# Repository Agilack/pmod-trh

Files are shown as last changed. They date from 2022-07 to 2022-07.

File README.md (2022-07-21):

PMOD Temperature and Humidity
=============================

This PMOD use an Si7021 sensor for temperature and humidity measurement.

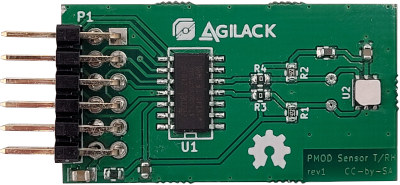
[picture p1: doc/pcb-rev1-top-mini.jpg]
Picture of PMOD-trh rev1


CAD source
----------

This board has been designed using KiCad EDA (version 6). All sources files
(schematics, routing, ...) are available into the `prj-kicad` folder. You can
re-use this design under terms of the Creative Commons  ShareAlike license
(CC-by-SA).

<table>
<tr>
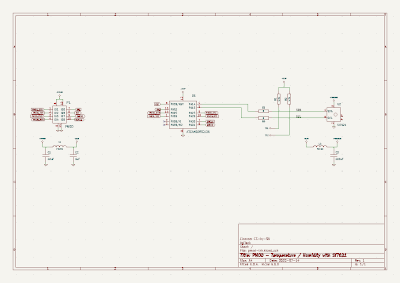
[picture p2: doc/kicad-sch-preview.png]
KiCad schematics
<td></td>
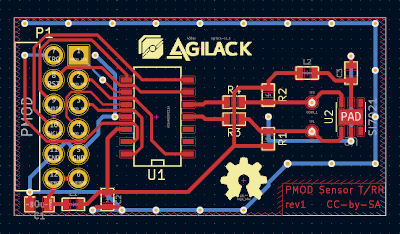
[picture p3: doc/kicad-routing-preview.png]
KiCad routing
<td></td>
</tr>
<tr>
<td>Fig1: Preview of the KiCad schematics</td>
<td>Fig2: Preview of the KiCad routing</td>
</tr>
</table>

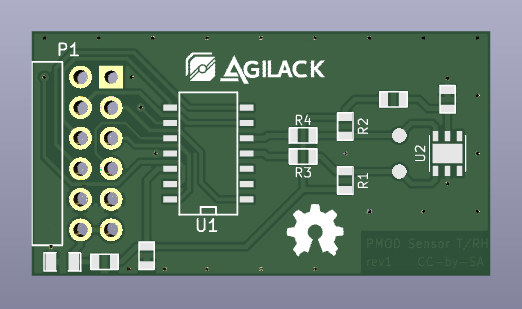
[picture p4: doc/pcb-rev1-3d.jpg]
PCB 3D preview


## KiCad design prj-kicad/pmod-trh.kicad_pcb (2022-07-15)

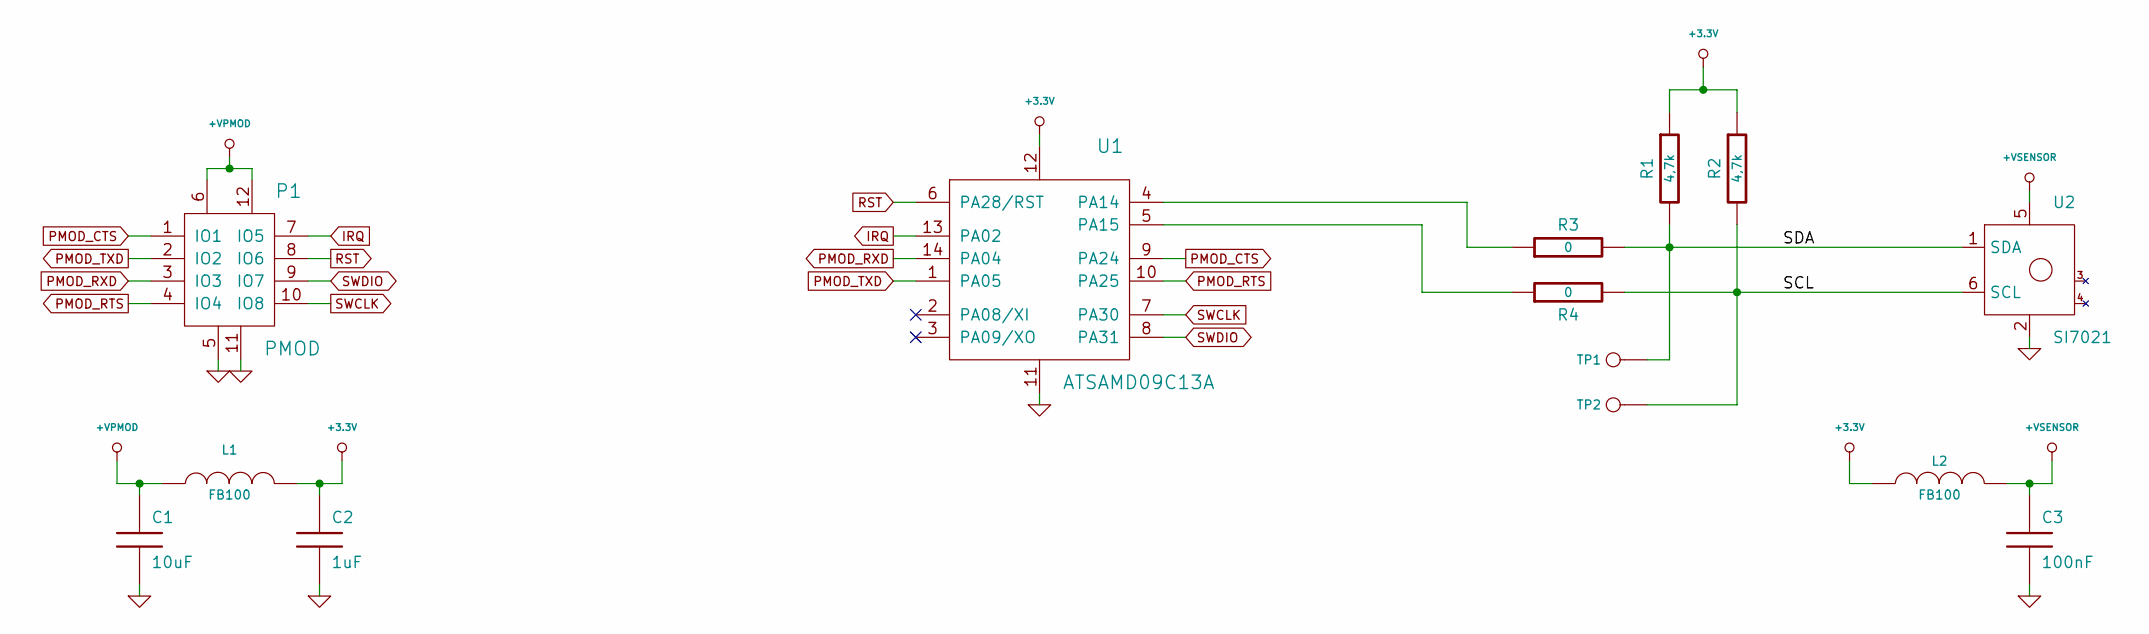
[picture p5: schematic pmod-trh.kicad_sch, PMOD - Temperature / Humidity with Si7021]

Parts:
C1: 10uF; SMD0805
C2: 1uF; SMD0603
C3: 100nF; SMD0603
L1, L2: FB100; SMD0603
P1: PMOD; CONN_PMOD-Male
R1, R2: 4,7k; SMD0603
R3, R4: 0; SMD0603
TP1, TP2: CONN_1; TP_SMD
U1: ATSAMD09C13A; SOIC-14
U2: SI7021; DFN6

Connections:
+3.3V: C2.1, L1.2, L2.1, R1.1, R2.1, U1.12
+VPMOD: C1.1, L1.1, P1.6, P1.12
+VSENSOR: C3.1, L2.2, U2.5
/SCL: R2.2, R4.2, TP2.1, U2.6 (SCL)
/SDA: R1.2, R3.2, TP1.1, U2.1 (SDA)
GND: C1.2, C2.2, C3.2, P1.5, P1.11, U1.11, U2.2
IRQ: P1.7 (IO5), U1.13 (PA02)
unnamed: R3.1, U1.4 (PA14)
unnamed: R4.1, U1.5 (PA15)
PMOD_CTS: P1.1 (IO1), U1.9 (PA24)
PMOD_RTS: P1.4 (IO4), U1.10 (PA25)
PMOD_RXD: P1.3 (IO3), U1.14 (PA04)
PMOD_TXD: P1.2 (IO2), U1.1 (PA05)
RST: P1.8 (IO6), U1.6 (PA28/RST)
SWCLK: P1.10 (IO8), U1.7 (PA30)
SWDIO: P1.9 (IO7), U1.8 (PA31)

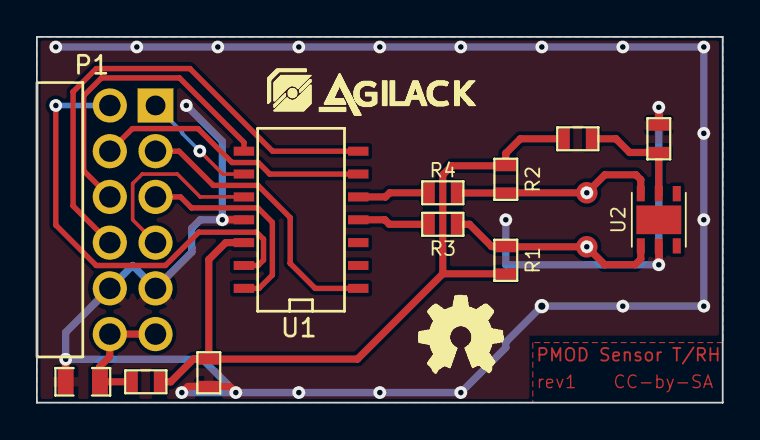
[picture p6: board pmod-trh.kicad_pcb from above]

Board: 2 copper layers, 38.1 x 20.3 mm, 16 parts (0 on the bottom side), 16 nets.

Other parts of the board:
agilack-11.5: 450px; logo-agilack-11.5
logo_ohw: VAL**; logo-ohw

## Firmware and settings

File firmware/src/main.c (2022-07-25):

/**
 * @file  main.c
 * @brief Entry point of the C code (main)
 *
 * @author Saint-Genest Gwenael <gwen@cowlab.fr>
 * @copyright Cowlab (c) 2022
 *
 * @page License
 * This firmware is free software: you can redistribute it and/or modify it
 * under the terms of the GNU General Public License version 3 as published
 * by the Free Software Foundation. You should have received a copy of the
 * GNU General Public License along with this program, see LICENSE.md file
 * for more details.
 * This program is distributed WITHOUT ANY WARRANTY.
 */
#include "hardware.h"
#include "i2c.h"
#include "uart.h"

/**
 * @brief Entry point of the C code (called by reset handler)
 *
 * @return integer Result of execution ... but should never return :)
 */
int main(void)
{
	/* Initialize clocks and low-level hardware */
	hw_init();
	/* Initialize peripherals */
	i2c_init();
	uart_init();

	uart_puts("PMOD-TRH: Started\r\n");

	while(1)
	{
		/* We will do something here later :p */
	}

	return(0);
}
/* EOF */

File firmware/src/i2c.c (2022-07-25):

/**
 * @file  i2c.c
 * @brief Handle I2C port (using sercom peripheral)
 *
 * @author Saint-Genest Gwenael <gwen@cowlab.fr>
 * @copyright Cowlab (c) 2022
 *
 * @page License
 * This firmware is free software: you can redistribute it and/or modify it
 * under the terms of the GNU General Public License version 3 as published
 * by the Free Software Foundation. You should have received a copy of the
 * GNU General Public License along with this program, see LICENSE.md file
 * for more details.
 * This program is distributed WITHOUT ANY WARRANTY.
 */
#include "hardware.h"
#include "i2c.h"

/* Bus frequency : ~100kHz with 8MHz GCLK */
#define CONF_I2C_BAUD (35 & 0xFF)

#define I2C_DEBUG

/**
 * @brief Initialize I2C driver
 *
 * This function initialize the sercom peripheral to use it as an I2C bus
 * master. For this driver to work properly, this function must be called
 * before any other i2c functions.
 */
void i2c_init(void)
{
	/* 1) Enable peripheral and set clocks */

	/* Enable SERCOM0 clock (APBCMASK) */
	reg_set(PM_ADDR + 0x20, (1 << 2));
	/* Set GCLK for SERCOM0 (generic clock generator 0) */
	reg16_wr (GCLK_ADDR + 0x02, (1 << 14) | (0 << 8) | 14);

	/* 2) Initialize sercom/I2C block   */

	/* Reset sercom (set SWRST)     */
	reg_wr((I2C_ADDR + 0x00), 0x01);
	/* Wait end of software reset */
	while( reg_rd(I2C_ADDR + 0x00) & 0x01)
		;
	/* Configure interface */
	reg_wr(I2C_ADDR + 0x00, (5 << 2));
	reg_wr(I2C_ADDR + 0x04, 0);
	/* Configure Baudrate */
	reg16_wr(I2C_ADDR + 0x0C, CONF_I2C_BAUD);
	/* Set ENABLE into CTRLA */
	reg_set(I2C_ADDR + 0x00, (1 << 1));

	/* 3) Configure pins (IOs) */

	/* PINCFG: Enable PMUX for SCL/SDA pins */
	reg8_wr(0x60000000 + 0x4E, 0x01); /* PA14 : SDA */
	reg8_wr(0x60000000 + 0x4F, 0x01); /* PA15 : SCL */
	/* Set peripheral function C (SERCOM) for PA14 and PA15 */
	reg8_wr(0x60000000 + 0x37, (0x02 << 4) | (0x02 << 0));
}

/**
 * @brief Read one byte received from I2C bus
 *
 * @param data  Pointer to a variable where readed value can be stored
 * @param again Boolean flag used to request another byte after current
 * @return integer Zero is returned on success, other values are errors
 */
int i2c_read (unsigned char *data, int again)
{
	unsigned long v;
	unsigned int  i;

#ifdef I2C_DEBUG
	/* Verify that I2C sercom is enabled and ready */
	if ((reg_rd(I2C_ADDR + 0x00) & (1 << 1)) == 0)
		return(-9);
#endif

	/* Wait end of transmission (SB or ERROR) */
	for (i = 0; i < I2C_RD_WAIT; i++)
	{
		/* Read INTFLAG */
		v = reg8_rd(I2C_ADDR + 0x18);
		if (v & 0x83)
			break;
		/* Read STATUS */
		v = reg16_rd(I2C_ADDR + 0x1A);
		//asm volatile("bkpt #0");
	}
	/* In case of timeout during wait, abort */
	if (i == I2C_RD_WAIT)
		return(-1);
	/* In case of an error, abort */
	if (v & 0x81)
		return(-2);

	/* Read received byte */
	v = reg16_rd(I2C_ADDR + 0x28);
	if (data)
		*data = (v & 0xFF);

	/* If "again" flag is set, initiate another read */
	if (again)
		reg_wr(I2C_ADDR + 0x04, (2 << 16));
	/* Else (last byte) set the acknowledge value to NACK */
	else
		reg_wr(I2C_ADDR + 0x04, (1 << 18));

	return(0);
}

/**
 * @brief Initiate communication with a slave byt sending START and address
 *
 * @param addr Address of the slave device
 * @param rw   Specify if transaction is a read (1) or a write (0)
 * @return integer Zero is returned on success, other values are errors
 */
int i2c_start(unsigned short addr, int rw)
{
	unsigned long v;
	unsigned int  i;

#ifdef I2C_DEBUG
	/* Verify that I2C sercom is enabled and ready */
	if ((reg_rd(I2C_ADDR + 0x00) & (1 << 1)) == 0)
		return(-9);
#endif

	/* If a previous error has not been cleared */
	v = reg8_rd(I2C_ADDR + 0x18);
	if (v & 0x80)
	{
		/* Read STATUS */
		v = reg16_rd(I2C_ADDR + 0x1A);
		/* Clear it now ! */
		reg8_wr(I2C_ADDR + 0x18, 0x80);
	}

	/* Send START, slave address and rw bit */
	v = ((addr << 1) & 0x7FE) | (rw & 1);
	reg_wr(I2C_ADDR + 0x24, v);

	/* Wait for MB or ERROR */
	for (i = 0; i < I2C_ST_WAIT; i++)
	{
		v = reg8_rd(I2C_ADDR + 0x18);
		if (v & 0x83)
			break;
	}
	/* In case of timeout during wait, abort */
	if (i == I2C_ST_WAIT)
		goto err;

	/* Read STATUS */
	v = reg16_rd(I2C_ADDR + 0x1A);
	if (v & 0x07)
		goto err;

	return(0);
err:
	/* Send a STOP condition */
	reg_wr(I2C_ADDR + 0x04, (0x03 << 16));
	/* Clear the ERROR bit */
	reg8_wr(I2C_ADDR + 0x18, 0x80);
	return(-1);
}

/**
 * @brief Terminate a transaction by sending a STOP condition on bus
 *
 * @return integer Zero is returned on success, other values are errors
 */
int i2c_stop(void)
{
	unsigned long v;

#ifdef I2C_DEBUG
	/* Verify that I2C sercom is enabled and ready */
	if ((reg_rd(I2C_ADDR + 0x00) & (1 << 1)) == 0)
		return(-9);
#endif

	/* Read the current acknowledge value */
	v = reg_rd(I2C_ADDR + 0x04) & (1 << 18);

	/* Send a STOP condition */
	reg_wr(I2C_ADDR + 0x04, v | (0x03 << 16));

	return(0);
}

/**
 * @brief Send a byte to the slave device
 *
 * @param data Value to send (byte) to the remote slave device
 * @return integer Zero is returned on success, other values are errors
 */
int i2c_write(unsigned char data)
{
	unsigned long v;

	v = reg8_rd(I2C_ADDR + 0x18);

	reg16_wr(I2C_ADDR + 0x28, data);

	// Wait for MB or ERROR
	do
		v = reg8_rd(I2C_ADDR + 0x18);
	while ( (v & 0x81) == 0);

	if (v & 0x80)
		return(-1);

	return(0);
}
/* EOF */

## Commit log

2022-07-14 --=={ Create Project }==--
    - Insert schematics and routing
    [pmod-trh.kicad_pcb, pmod-trh.kicad_sch]
2022-07-15 = ADD: Create production files for rev1
    [pmod-trh-B_Cu.gbr, pmod-trh-B_Mask.gbr, pmod-trh-B_Paste.gbr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]
2022-07-21 = UPD: Insert picture of the first PCB \o/ ; update readme
